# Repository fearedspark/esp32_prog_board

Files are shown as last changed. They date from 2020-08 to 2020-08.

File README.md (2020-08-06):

# ESP32 Programming/Debugging Board

This project is a simple board to program and debug ESP32 chip using a USB-C port.

The core is a CP2104 USB-to-Serial converter and it uses the `RTS` and `DTS` signals to reset the MCU in boot mode for programming.

The programming post is a 6-pins JST PH SMT connector, with the following mapping:

|Pin #|Signal Name|Note |
|:---:|---|---|
|1 |+3.3V | |
|2 |GND | |
|3 |TX |From host to target |
|4 |RX |From target to host |
|5 |RESET |The board has a button shorting this line to GND|
|6 |BOOT0 |Should be connected directly to GPIO0 |

## Bill of Material

You can find the BOM on Octopart via this [link](https://octopart.com/bom-tool/CL9CJzFa).

|Reference Designator|Manufacturer |Product Number |Description |Quantity|Value|Tolerance|Rating|Package |
|---|---|---|---|---|-----|---|---|---|
|U1 |Diodes Inc. |AP2112K-3.3 |3.3V 600mA LDO w/ EN |1 | | | |SOT25 |
|U2 |Silicon Labs |CP2104 |USB-to-UART Bridge |1 | | | |QFN-24 |
|ESD1 |ON Semiconductor|ESD5B5.0ST1G |TVS Diode 5V |1 | | | |SOD523 |
|ESD2 |LittelFuse |SP3401 |TVS Diode Arrays for USB |1 | | | |JEDEC MO-229|
|D1 |Würth Elektronik|150060RS75000 |Red LED |1 | | | |0603 |
|D2 |Würth Elektronik|150060GS75000 |Green LED |1 | | | |0603 |
|D3 |Würth Elektronik|150060BS75000 |Blue LED |1 | | | |0603 |
|Q1 |Diodes Inc. |MMDT2222A |Dual Small Signal NPN Transistor|1 | | | |SOT363 |
|C1, C2, C4 | | |10µF, 10V SMT Ceramic Capacitor |3 |10µF |≤±20% |≥10V  |0603 |
|C3 | | |1µF, 10V SMT Ceramic Capacitor  |1 |1µF  |≤±20% |≥10V  |0603 |
|C5\* | | |4.7µF, 10V SMT Ceramic Capacitor|1 |4.7µF|≤±20% |≥10V  |0603 |
|R1, R2 | | |5.1kΩ SMT Resistor |2 |5.1kΩ|≤±1% | |0603 |
|R3 | | |100kΩ SMT Resistor |1 |100kΩ|≤±5% | |0603 |
|R4, R5, R6 | | |10kΩ SMT Resistor |3 |10kΩ |≤±5% | |0603 |
|R7 | | |330Ω |1 |330Ω |≤±5% | |0603 |
|R8 | | |120Ω |1 |120Ω |≤±5% | |0603 |
|R9 | | |91Ω |1 |91Ω  |≤±5% | |0603 |
|J1 |Molex |105450-0101 |USB-C SMT Connector |1 | | | | |
|J2 |JST Inc. |S6B-PH-SM4-TB(LF)(SN)|6-Pins SMT JST PH Connector |1 | | | | |

> Notes:
> - \*`C5` is only required to modify the device OTP memory. It can be ignored.
> - Red LED is for power, Blue LED is for host RX, Green LED is for host TX.

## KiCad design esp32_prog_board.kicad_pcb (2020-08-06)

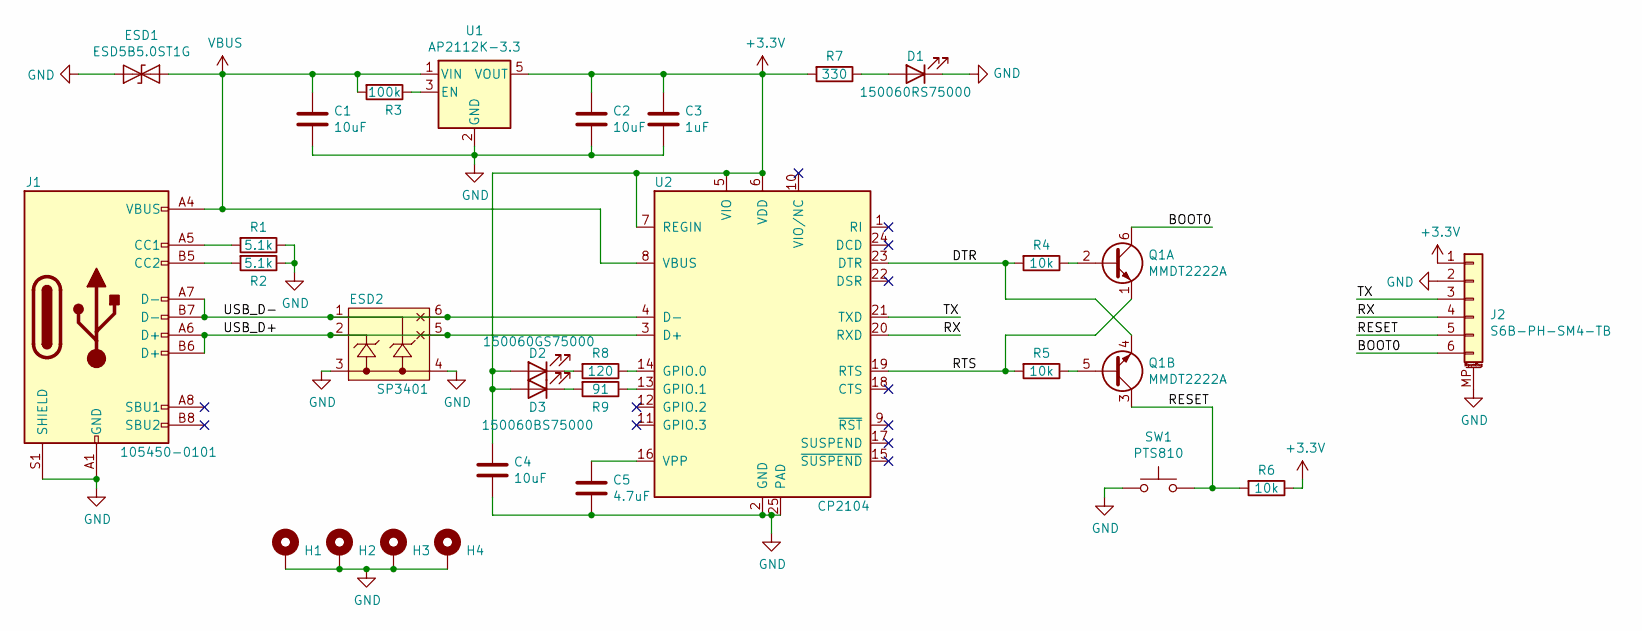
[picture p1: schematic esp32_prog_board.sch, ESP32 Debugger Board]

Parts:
C1, C2, C4: 10uF; R_0603_1608Metric
C3: 1uF; R_0603_1608Metric
C5: 4.7uF; R_0603_1608Metric
D1: 150060RS75000; LED_0603_1608Metric
D2: 150060GS75000; LED_0603_1608Metric
D3: 150060BS75000; LED_0603_1608Metric
ESD1: ESD5B5.0ST1G; D_SOD-523
ESD2: SP3401
H1, H2, H3, H4: MountingHole_Pad; MountingHole_2.7mm_M2.5_Pad
J1: 105450-0101
J2: S6B-PH-SM4-TB; JST_PH_S6B-PH-SM4-TB_1x06-1MP_P2.00mm_Horizontal
Q1: MMDT2222A; SOT-363_SC-70-6
R1, R2: 5.1k; R_0603_1608Metric
R3: 100k; R_0603_1608Metric
R4, R5, R6: 10k; R_0603_1608Metric
R7: 330; R_0603_1608Metric
R8: 120; R_0603_1608Metric
R9: 91; R_0603_1608Metric
SW1: PTS810; SW_SPST_PTS810
U1: AP2112K-3.3; SOT-23-5
U2: CP2104; QFN-24-1EP_4x4mm_P0.5mm_EP2.6x2.6mm

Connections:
+3V3: C2.1, C3.1, C4.1, D2.2 (A), D3.2 (A), J2.1, R6.1, R7.2, U1.5 (VOUT), U2.5 (VIO), U2.6 (VDD), U2.7 (REGIN)
/BOOT0: J2.6, Q1.6 (C1)
/DTR: Q1.4 (E2), R4.2, U2.23 (DTR)
/RESET: J2.5, Q1.3 (C2), R6.2, SW1.2
/RTS: Q1.1 (E1), R5.2, U2.19 (RTS)
/RX: J2.4, U2.20 (RXD)
/TX: J2.3, U2.21 (TXD)
/USB_D+: ESD2.2, ESD2.5, J1.A6 (D+), J1.B6 (D+), U2.3 (D+)
/USB_D-: ESD2.1, ESD2.6, J1.A7 (D-), J1.B7 (D-), U2.4 (D-)
GND: C1.2, C2.2, C3.2, C4.2, C5.2, D1.1 (K), ESD1.1 (A1), ESD2.3, ESD2.4, H1.1, H2.1, H3.1, H4.1, J1.A1 (GND), J1.A12 (GND), J1.B1 (GND), J1.B12 (GND), J1.S1 (SHIELD), J2.2, J2.MP (MountPin), R1.1, R2.1, SW1.1, U1.2 (GND), U2.2 (GND), U2.25 (PAD)
unnamed: C5.1, U2.16 (VPP)
unnamed: D1.2 (A), R7.1
unnamed: D2.1 (K), R8.2
unnamed: D3.1 (K), R9.2
unnamed: J1.A5 (CC1), R1.2
unnamed: J1.B5 (CC2), R2.2
unnamed: Q1.2 (B1), R4.1
unnamed: Q1.5 (B2), R5.1
unnamed: R3.1, U1.3 (EN)
unnamed: R8.1, U2.14 (GPIO.0)
unnamed: R9.1, U2.13 (GPIO.1)
VBUS: C1.1, ESD1.2 (A2), J1.A4 (VBUS), J1.A9 (VBUS), J1.B4 (VBUS), J1.B9 (VBUS), R3.2, U1.1 (VIN), U2.8 (VBUS)

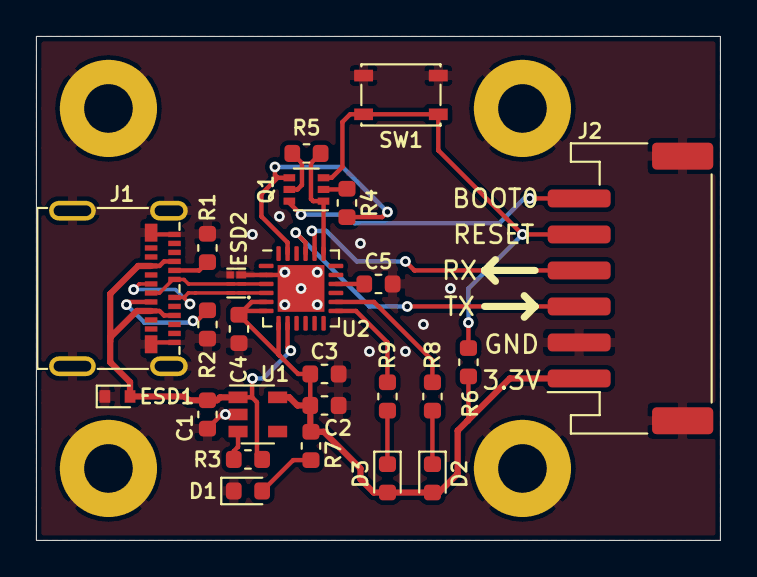
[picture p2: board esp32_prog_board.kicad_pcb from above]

Board: 2 copper layers, 38.0 x 28.0 mm, 29 parts (0 on the bottom side), 22 nets.

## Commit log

2020-08-04 Created project
    [esp32_prog_board.kicad_pcb, esp32_prog_board.sch]
2020-08-04 Added Molex USB-C connector footprint
2020-08-05 Completed schematic
    [esp32_prog_board.sch]
2020-08-05 Updated BOM
2020-08-05 Added VBUS ESD, and TX/RX/PWR LEDs
    [esp32_prog_board.sch]
2020-08-06 Completed routing
    [esp32_prog_board.kicad_pcb, esp32_prog_board.sch]
2020-08-06 Added Octopart BOM link
